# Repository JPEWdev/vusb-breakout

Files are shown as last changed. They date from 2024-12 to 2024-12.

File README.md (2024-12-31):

# vusb-breakout
KiCAD PCB design for a V-USB breakout board

This breadboard compatible board has all the components required for a
[V-USB][1] based project, suitable for connecting directly to the pins of an
Atmel.

Features include:

1. Voltage limiting Zener diodes on D+ and D- so the Atmel can be run anywhere
   between 3.3 and 5 V
2. Ability to be powered from USB (if jumper is set) and/or external power (via
   Vin pin). Schottky diodes prevent back-power in both cases.
3. USB ID pin is broken out

NOTE: If running the Atmel at 5V, the board will draw about 20 mA from either
D+ or D- when they are driven high.

[1]: https://www.obdev.at/products/vusb/index.html

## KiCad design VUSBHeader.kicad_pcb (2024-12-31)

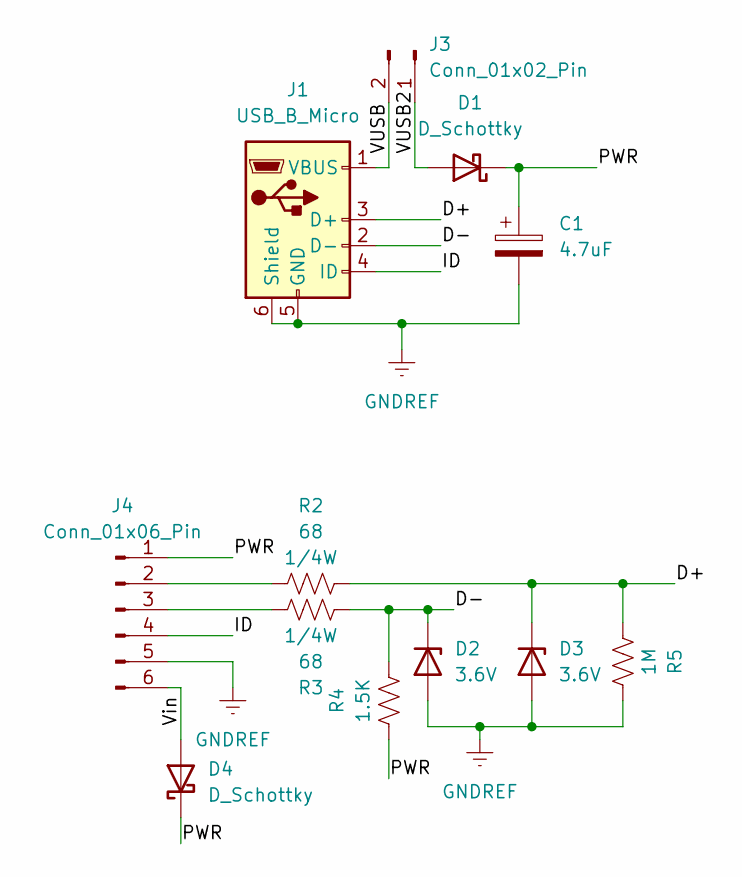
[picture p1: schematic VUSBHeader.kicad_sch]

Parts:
C1: 4.7uF; CP_Radial_D5.0mm_P2.50mm
D1, D4: D_Schottky; D_SOD-123
D2, D3: 3.6V; D_SOD-123
J1: USB_B_Micro; USB_Micro-B_Wuerth_629105150521
J3: Conn_01x02_Pin; PinHeader_1x02_P2.54mm_Vertical
J4: Conn_01x06_Pin; PinHeader_1x06_P2.54mm_Vertical
R2, R3: 68; R_0603_1608Metric_Pad0.98x0.95mm_HandSolder
R4: 1.5K; R_0603_1608Metric_Pad0.98x0.95mm_HandSolder
R5: 1M; R_0603_1608Metric_Pad0.98x0.95mm_HandSolder

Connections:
/D+: D3.1 (K), J1.3 (D+), R2.2, R5.2
/D-: D2.1 (K), J1.2 (D-), R3.2, R4.1
/ID: J1.4 (ID), J4.4
/PWR: C1.1, D1.1 (K), D4.1 (K), J4.1, R4.2
/VUSB: J1.1 (VBUS), J3.2
/VUSB2: D1.2 (A), J3.1
/Vin: D4.2 (A), J4.6
GNDREF: C1.2, D2.2 (A), D3.2 (A), J1.5 (GND), J1.6 (Shield), J4.5, R5.1
unnamed: J4.2, R2.1
unnamed: J4.3, R3.1

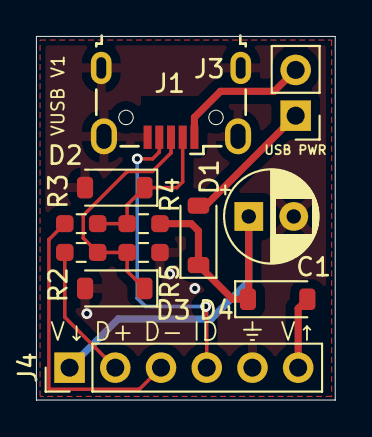
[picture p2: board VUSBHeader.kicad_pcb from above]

Board: 2 copper layers, 16.6 x 20.2 mm, 12 parts (0 on the bottom side), 10 nets.

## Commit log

2024-12-24 Initial Commit
    Initial Commit
    [VUSBHeader.kicad_pcb, VUSBHeader.kicad_sch]
2024-12-31 Fix D- and D+ labeling
    The D- and D+ labels were swapped on the board, so correct them. Also
    update the README and move the manufacturing notes to make them easier
    to read
    [VUSBHeader.kicad_pcb]
